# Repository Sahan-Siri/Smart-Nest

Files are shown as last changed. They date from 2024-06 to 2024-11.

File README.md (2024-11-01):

# Smart-Nest
## Undergraduate Product Designing Project

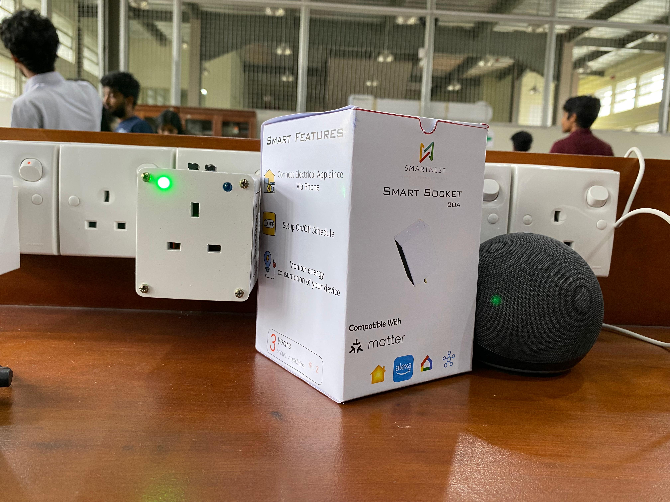
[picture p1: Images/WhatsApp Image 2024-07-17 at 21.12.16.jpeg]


### Overview

Welcome to the Smart Socket with Power Monitoring and Control! This smart socket allows you to monitor power consumption and control your devices remotely using a mobile device or smart hubs like Amazon Alexa, Google Home, and other devices compatible with the Matter protocol.

### Features

- **Remote Control:** Turn your devices on or off from anywhere using your mobile device.
- **Power Monitoring:** Keep track of your device's power consumption in real time.
- **Smart Hub Integration:** Seamlessly integrate with Amazon Alexa, Google Home, and other Matter-compatible devices.
- **Scheduling:** Set schedules to automate your devices' on/off times.
- **Energy Saving:** Monitor and reduce your energy usage, helping you save on electricity bills.
- **Voice Control:** Use voice commands to control your devices through smart hubs.

### Requirements

- A mobile device with iOS or Android
- A smart hub (Amazon Alexa, Google Home, or any Matter-compatible device)
- Wi-Fi connection

### Installation and Setup

#### 1. Hardware Installation

1. **Plug in the Smart Socket:**
   - Insert the Smart Socket into a standard electrical outlet.
   - Ensure that the socket is securely in place.

2. **Connect Your Device:**
   - Plug the device you want to control into the Smart Socket.

#### 2. App Installation

1. **Download the Mobile App:**
   - For iOS, visit the [App Store](https://www.apple.com/app-store/) and search for "Smart Nest."
   - For Android, visit the [Google Play Store](https://play.google.com/store) and search for "Smart Nest."

2. **Create an Account:**
   - Open the app and follow the on-screen instructions to create a new account or log in if you already have one.

3. **Add Your Smart Socket:**
   - In the app, tap on "Add Device" and select "Smart Socket."
   - Follow the on-screen instructions to connect the Smart Socket to your Wi-Fi network.

#### 3. Smart Hub Integration

1. **Amazon Alexa:**
   - Open the Alexa app and go to the "Devices" tab.
   - Tap on "Add Device" and select "Plug."
   - Follow the instructions to link your Smart Socket with Alexa.

2. **Google Home:**
   - Open the Google Home app and tap on the "+" icon to add a new device.
   - Select "Set up device" and choose "Works with Google."
   - Search for "Smart Socket Control" and follow the instructions to link your Smart Socket.

3. **Other Matter-Compatible Devices:**
   - Refer to your specific smart hub’s instructions for adding a new Matter-compatible device.
   - Look for "Smart Socket Control" and follow the setup instructions.

### Usage

#### Remote Control

1. **Using the Mobile App:**
   - Open the app and select your Smart Socket.
   - Use the on/off button to control the connected device.

2. **Using Smart Hubs:**
   - For Alexa: Say, "Alexa, turn on [Device Name]."
   - For Google Home: Say, "Hey Google, turn off [Device Name]."

#### Power Monitoring

1. **Real-Time Monitoring:**
   - Open the mobile app and select your Smart Socket.
   - View real-time power consumption data on the main dashboard.

2. **Historical Data:**
   - Access historical power consumption data from the "History" tab in the app.

#### Scheduling

1. **Set Schedules:**
   - In the mobile app, go to the "Schedules" tab.
   - Add a new schedule by selecting the time and days for the device to turn on/off.

### Troubleshooting

- **Smart Socket Not Connecting:**
  - Ensure that your Wi-Fi network is 2.4 GHz (not 5 GHz).
  - Restart your router and try again.
  - Make sure the Smart Socket is within range of your Wi-Fi network.

- **Device Not Responding:**
  - Check if the Smart Socket is properly plugged in and powered.
  - Ensure that your mobile device and smart hub are connected to the same Wi-Fi network.

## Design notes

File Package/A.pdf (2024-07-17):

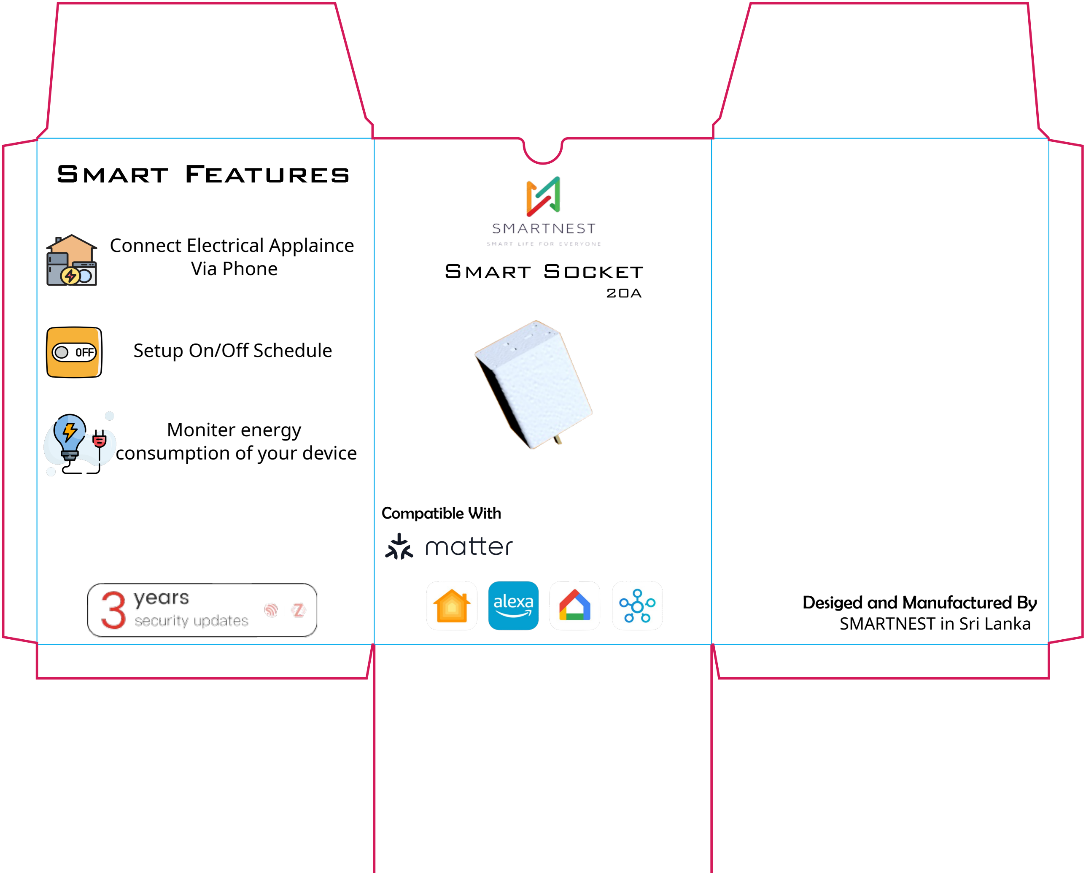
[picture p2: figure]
Smart Socket; Compatible With; Smart Features; Connect Electrical Applaince Via Phone; Setup On/Off Schedule; Moniter energy consumption of your device; Desiged and Manufactured By SMARTNEST in Sri Lanka

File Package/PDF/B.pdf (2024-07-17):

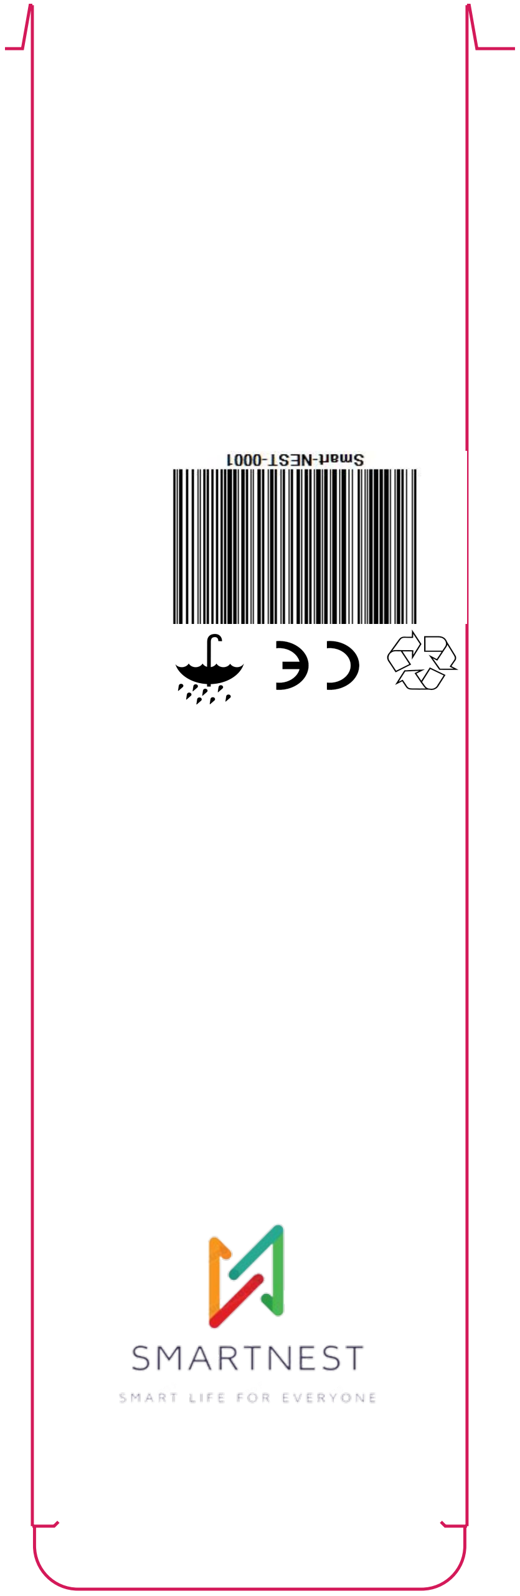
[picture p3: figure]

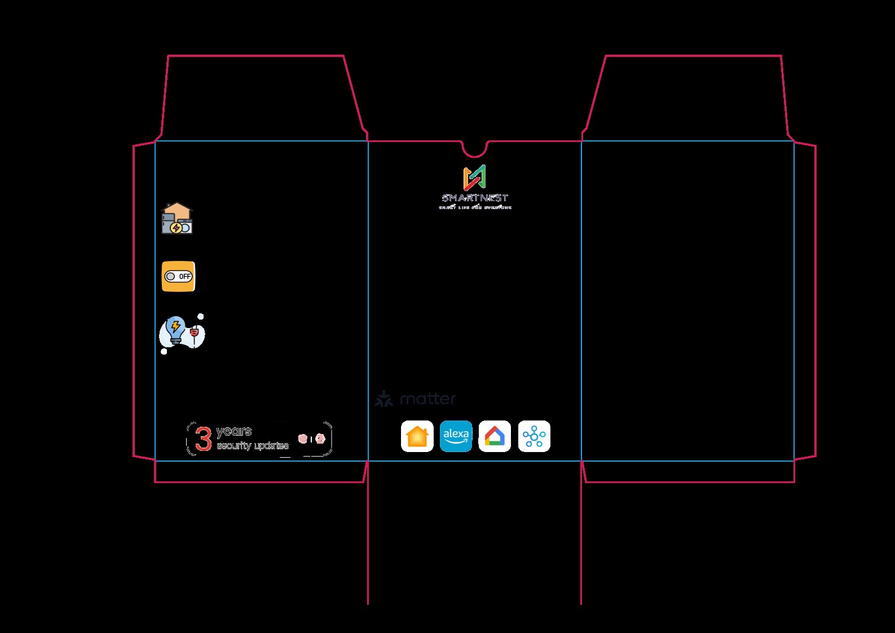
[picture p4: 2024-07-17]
Package/drawing.jpg

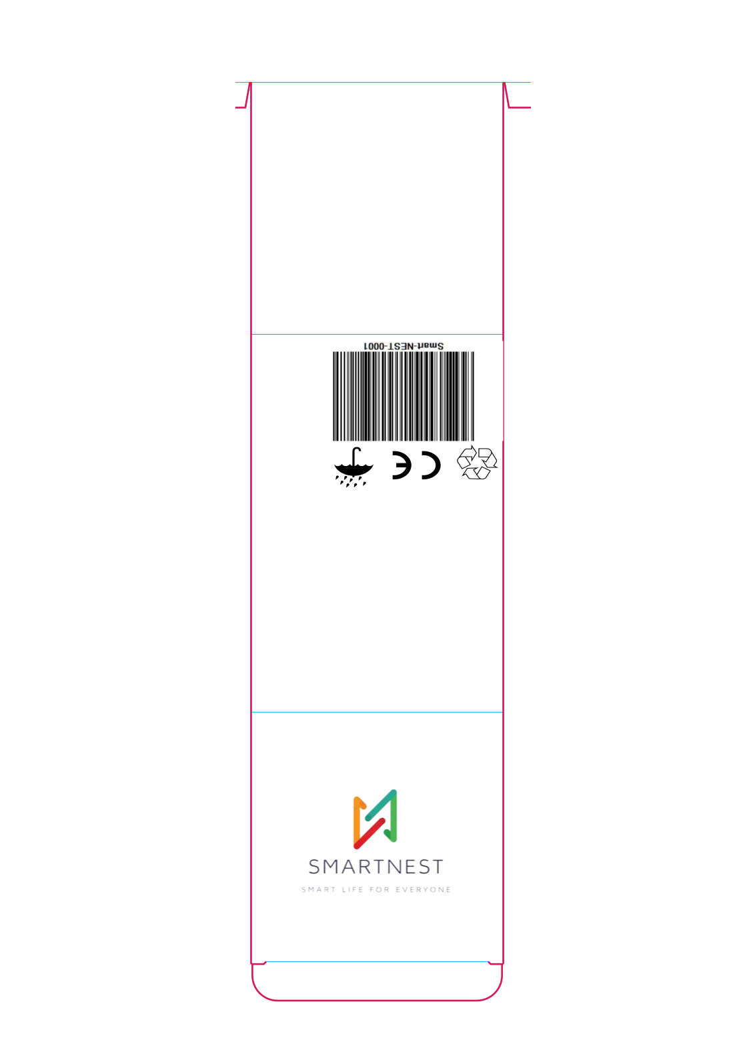
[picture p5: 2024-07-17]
Package/drawing-1.png

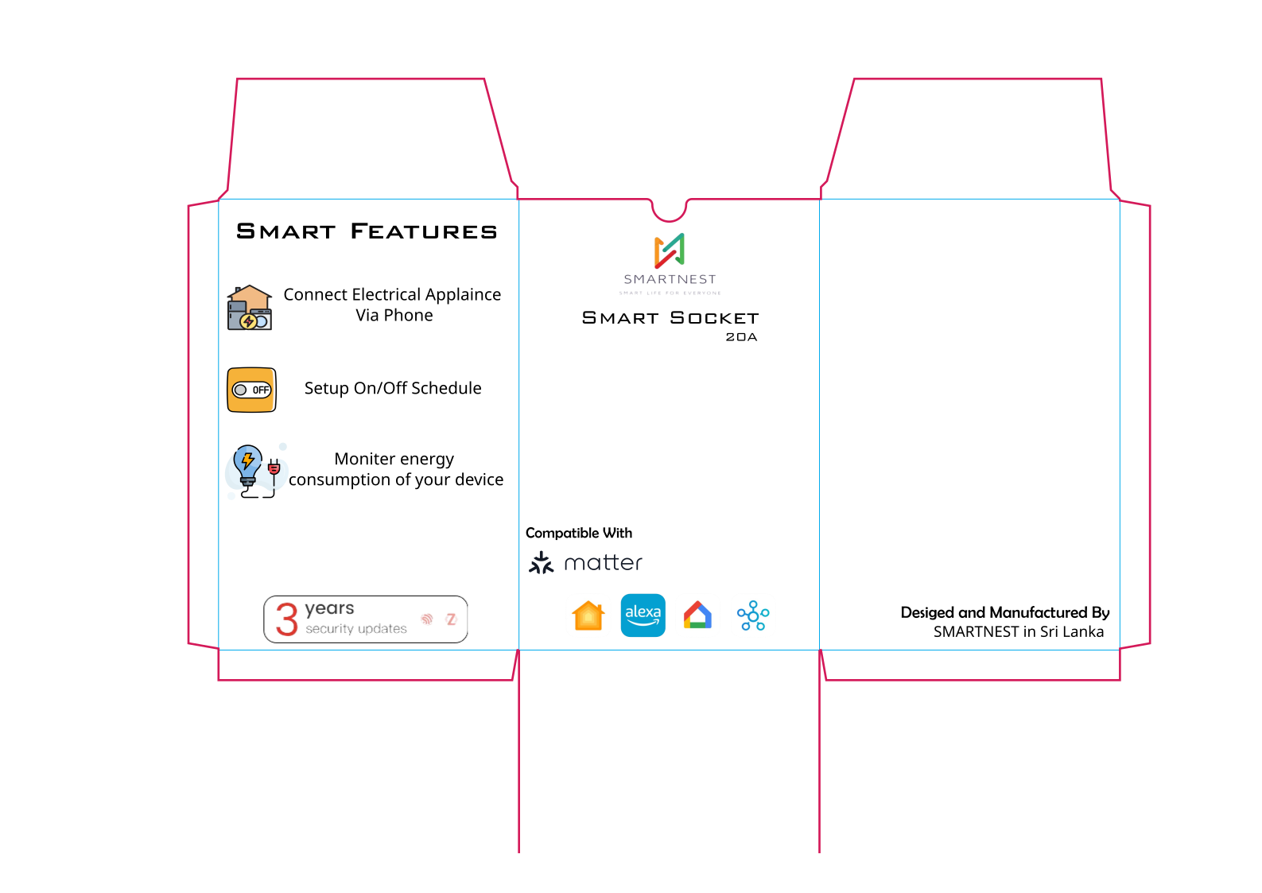
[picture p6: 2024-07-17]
Package/drawing.png

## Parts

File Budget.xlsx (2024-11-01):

Budget For Smart Nest |  |  |  |  |  |  | Donation
Item | Quantity | Unity Price | Total Price |  |  |  | Sahan Siri | Sahan Sera | Mari | Maha
ESP32 C3 Mini | 2 | 875.45 | 1750.9 | 1750 | 16510.32 |  | 3350.42 | 1354 | 900 | 0
JCL PCB | 5 | 3350.42 | 3350.42 | 600 |  |  | 1750.9 | 300 | 545 | 550
Fenale Pin Header | 8 | 40 | 320 | 0 |  |  |  |  | 1200 | 6200
Circuit Wire 10/0.5mm | 8 | 30 | 240 | 240
Volatage Sensor | 1 | 550 | 550 | 450
Current Sensor | 1 | 545 | 545 | 400
AC to DC Converter | 2 | 450 | 900 | 700
Terminal Block Connector | 6 | 35 | 210 | 0
T-mount Screw Terminal | 2 | 45 | 90 | 0
ESP32 | 0 | 1790 | 0 | 0
Full Set |  |  | 1354 | 1354
3D print | 1 | 6200 | 6200 | 3800
atmega | 1 | 1000 | 1000 | 990
 |  |  |  | 10284
 |  |  |  |  |  | Total= | 5101.32 | 1654 | 2645 | 6750
 |  |  |  |  |  | Each One Gets= | 4127.58 | 4127.58 | 4127.58 | 4127.58
 |  |  |  |  |  | Remaining= | -973.74 | 2473.58 | 1482.58 | -2622.42

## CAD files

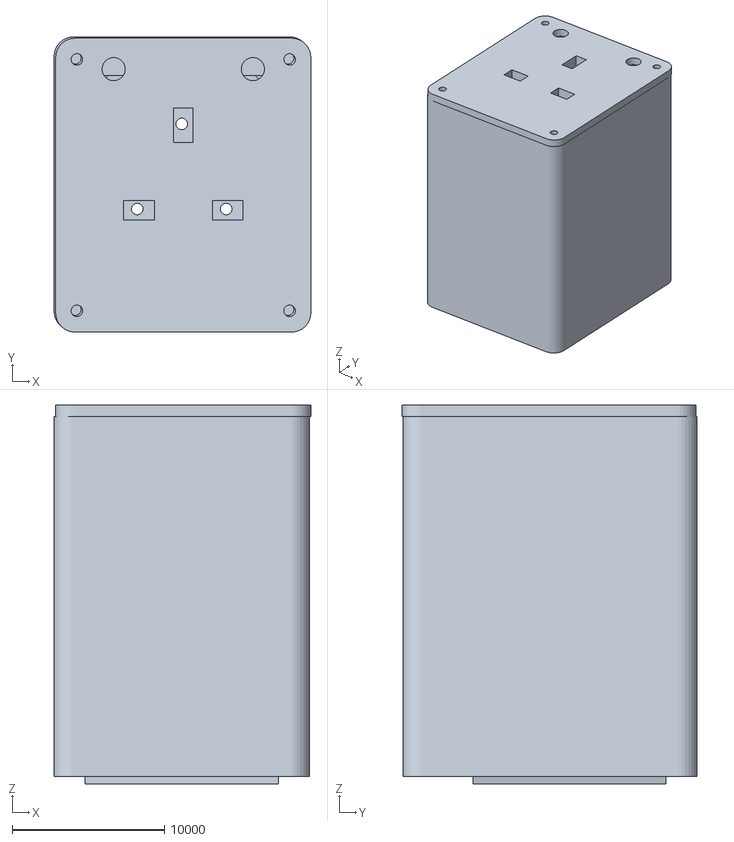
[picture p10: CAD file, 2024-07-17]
3D Model/02.dxf
16865.5 x 19386.5 x 24892.0

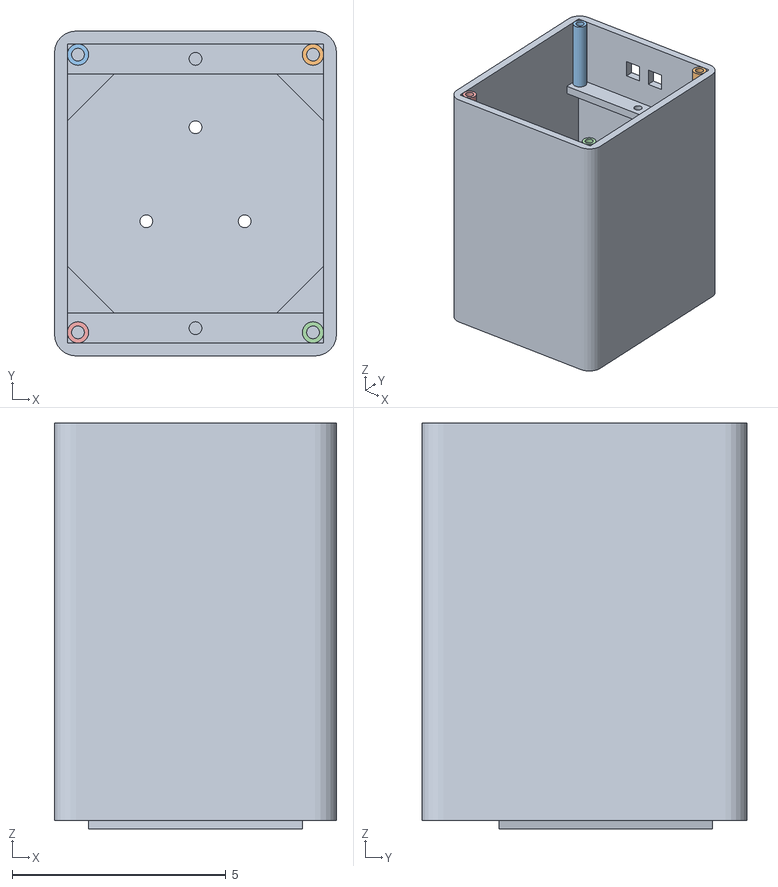
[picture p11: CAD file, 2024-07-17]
3D Model/PCB/Down_Layer v25.obj
6.60 x 7.60 x 9.50

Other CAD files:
3D Model/PCB/SmartNest_PCB v3.dwg
3D Model/03.dwg
3D Model/02.dwg
3D Model/PCB/Down_Layer v27/Down_Layer.iam
3D Model/PCB/Down_Layer v27/Part4.ipt
3D Model/PCB/Down_Layer v27/Upper Layer.ipt
3D Model/PCB/Down_Layer v36.f3d
3D Model/PCB/Upper_Layer v14.f3d
PCB/smart_plug_new v2.f3z

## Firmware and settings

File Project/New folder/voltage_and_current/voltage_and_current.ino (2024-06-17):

// EmonLibrary examples openenergymonitor.org, Licence GNU GPL V3

#include "EmonLib.h"             // Include Emon Library
EnergyMonitor emon1;             // Create an instance

void setup()
{  
  Serial.begin(115200);
  
  emon1.voltage(35, 234.26, 1.7);  // Voltage: input pin, calibration, phase_shift
  emon1.current(34, 4.5);       // Current: input pin, calibration.
}

void loop()
{
  emon1.calcVI(20,2000);         // Calculate all. No.of half wavelengths (crossings), time-out
  //emon1.serialprint();           // Print out all variables (realpower, apparent power, Vrms, Irms, power factor)
  
  float realPower       = emon1.realPower;        //extract Real Power into variable
  //float apparentPower   = emon1.apparentPower;    //extract Apparent Power into variable
  //float powerFActor     = emon1.powerFactor;      //extract Power Factor into Variable
  float supplyVoltage   = emon1.Vrms;             //extract Vrms into Variable
  float Irms            = emon1.Irms; 
  Serial.print("Voltage:");            //extract Irms into Variable
  Serial.println(supplyVoltage);
  Serial.print("Current:");
  Serial.println(Irms);
  Serial.print("Power:");
  Serial.println(realPower);
}

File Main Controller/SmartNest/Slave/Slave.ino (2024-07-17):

#include <Wire.h>
#include <WiFiManager.h>
#include <EEPROM.h>
#include <Firebase_ESP_Client.h>
#include "addons/TokenHelper.h"
#include "addons/RTDBHelper.h"

#define Button 7
#define EEPROM_SIZE 100
#define PATH_ADDRESS 0
#define API_KEY "AD API"
#define DATABASE_URL "ADD URL"

String Path;
String Old="Off";
FirebaseData fbdo;
FirebaseAuth auth;
FirebaseConfig config;
WiFiManager wm;

float number1, number2, number3;
byte buffer[12]; // 3 floats * 4 bytes each = 12 bytes
int bufferIndex = 0;

unsigned long sendDataPrevMillis = 0;
bool signupOK = false;

volatile bool resetFlag = false;
unsigned long buttonPressTime = 0;
bool buttonPressed = false;

void IRAM_ATTR handleButtonPress() {
  if (digitalRead(Button) == LOW) { // Button is pressed
    if (!buttonPressed) {
      buttonPressed = true;
      buttonPressTime = millis();
    }
  } else { // Button is released
    buttonPressed = false;
  }
}

void saveStringToEEPROM(int address, String data) {
  for (int i = 0; i < data.length(); ++i) {
    EEPROM.write(address + i, data[i]);
  }
  EEPROM.write(address + data.length(), '\0');
  EEPROM.commit();
}

String readStringFromEEPROM(int address) {
  char data[50];
  for (int i = 0; i < 50; ++i) {
    data[i] = EEPROM.read(address + i);
    if (data[i] == '\0') break;
  }
  return String(data);
}

float roundToTwoDecimalPlaces(float value) {
  return roundf(value * 100.0) / 100.0;
}

void setup() {
  pinMode(Button, INPUT_PULLUP);
  attachInterrupt(digitalPinToInterrupt(Button), handleButtonPress, CHANGE);
  pinMode(6, OUTPUT);
  pinMode(5, OUTPUT);
  pinMode(10, INPUT);
  Serial.begin(115200);
  WiFi.mode(WIFI_STA);

  EEPROM.begin(EEPROM_SIZE);

  Path = readStringFromEEPROM(PATH_ADDRESS);
  wm.setDebugOutput(false);

  WiFiManagerParameter Email_Box("Email", "Enter your E-mail here", "", 50);
  WiFiManagerParameter Location_Box("Location", "Location Name", "", 50);
  WiFiManagerParameter Name_Box("Name", "Name the Socket", "", 50);
  wm.addParameter(&Email_Box);
  wm.addParameter(&Location_Box);
  wm.addParameter(&Name_Box);

  bool res = wm.autoConnect("SmartNest", "password");
  if (!res) {
    Serial.println("Failed to connect");
  } else {
    Serial.println("Connected... yeey :)");
  }

  if (Path == "/0") {
    String Email = Email_Box.getValue();
    String Location = Location_Box.getValue();
    String Socket = Name_Box.getValue();

    int atIndex = Email.indexOf('@');
    if (atIndex != -1) {
      Email = Email.substring(0, atIndex);
    }
    atIndex = Location.indexOf(' ');
    if (atIndex != -1) {
      Location = Location.substring(0, atIndex);
    }
    atIndex = Socket.indexOf(' ');
    if (atIndex != -1) {
      Socket = Socket.substring(0, atIndex);
    }
    Path = Email + "/" + Location + " " + Socket;
    saveStringToEEPROM(PATH_ADDRESS, Path);
  }

  config.api_key = API_KEY;
  auth.user.email = "Device01@smartnest.com";
  auth.user.password = "Smart@1234";
  config.database_url = DATABASE_URL;
  config.token_status_callback = tokenStatusCallback;

  Firebase.begin(&config, &auth);
  Firebase.reconnectWiFi(true);
  signupOK = true;
  Wire.begin(8); // Join I2C bus with address #8
  Wire.onReceive(receiveEvent); // Register event
  if (digitalRead(10)==0){
    Firebase.RTDB.setString(&fbdo, Path + "/Switch","On");
    Old="On";
  }
  if (digitalRead(10)==1){
    Firebase.RTDB.setString(&fbdo, Path + "/Switch","Off");
    Old="Off";
  }
}

void loop() {
  if (buttonPressed && (millis() - buttonPressTime >= 3000)) {
    resetFlag = true;
    buttonPressed = false;
  }

  if (resetFlag) {
    resetFlag = false;
    Serial.println("Resetting WiFiManager settings...");
    wm.resetSettings();
    Path = "/0";
    saveStringToEEPROM(PATH_ADDRESS, Path);
    digitalWrite(6, LOW);
    delay(1000);
    ESP.restart();
  }

  if (WiFi.isConnected()) {
    digitalWrite(6, HIGH);
  } else {
    digitalWrite(6, LOW);
  }
  Serial.println(Path);

  if (Firebase.ready() && signupOK) {
    if (Old=="On" && digitalRead(10)==1){
      Firebase.RTDB.setString(&fbdo, Path + "/Switch","Off");
      Old="Off";
    }
    if (Old=="Off" && digitalRead(10)==0){
      Firebase.RTDB.setString(&fbdo, Path + "/Switch","On");
      Old="On";
    }
    if (Firebase.RTDB.getString(&fbdo, Path + "/Switch")) {
      String switchValue = fbdo.stringData();
      switchValue = switchValue.substring(2, switchValue.length() - 2);
      Serial.println(switchValue);
      if ((switchValue == "On") && (switchValue!=Old) && digitalRead(10)==1) {
        digitalWrite(5, HIGH);
        delay(100);
        digitalWrite(5, LOW);
        Old=switchValue;
      } 
      if ((switchValue == "Off") && (switchValue!=Old) && digitalRead(10)==0) {
        digitalWrite(5, HIGH);
        delay(100);
        digitalWrite(5, LOW);
        Old=switchValue;
      }
       
    } else {
      Serial.println("Failed to get switch value: " + fbdo.errorReason());
      ESP.restart();
    }

    if (millis() - sendDataPrevMillis > 5000 || sendDataPrevMillis == 0) {
      sendDataPrevMillis = millis();
      float roundedNumber1 = roundToTwoDecimalPlaces(number1);
      float roundedNumber2 = roundToTwoDecimalPlaces(number2);
      float roundedNumber3 = roundToTwoDecimalPlaces(number3);

      if (Old=="Off"){
        roundedNumber1=0.00;
        roundedNumber2=0.00;
        roundedNumber3=0.00;
      }

      if (Firebase.RTDB.setFloat(&fbdo, Path + "/Power", roundedNumber1)) {
        Serial.println(roundedNumber1);
        Serial.println("Power value set successfully");
      } else {
        Serial.println("Failed to set Power value: " + fbdo.errorReason());
        ESP.restart();
      }

      if (Firebase.RTDB.setFloat(&fbdo, Path + "/Voltage", roundedNumber2)) {
        Serial.println(roundedNumber2);
        Serial.println("Voltage value set successfully");
      } else {
        Serial.println("Failed to set Voltage value: " + fbdo.errorReason());
        ESP.restart();
      }

      if (Firebase.RTDB.setFloat(&fbdo, Path + "/Current", roundedNumber3)) {
        Serial.println(roundedNumber3);
        Serial.println("Current value set successfully");
      } else {
        Serial.println("Failed to set Current value: " + fbdo.errorReason());
        ESP.restart();
      }
    }
  } else {
    Serial.println("Firebase not ready or sign-up not completed");
    ESP.restart();
  }

  delay(1000);
  fbdo.clear();
}

void receiveEvent(int howMany) {
  while (Wire.available() && bufferIndex < 12) {
    buffer[bufferIndex++] = Wire.read();
  }
  if (bufferIndex >= 12) { // We have received 12 bytes
    bufferIndex = 0;
    // Cast bytes to float variables
    number1 = *((float*)&buffer[0]);
    number2 = *((float*)&buffer[4]);
    number3 = *((float*)&buffer[8]);
  }
}
